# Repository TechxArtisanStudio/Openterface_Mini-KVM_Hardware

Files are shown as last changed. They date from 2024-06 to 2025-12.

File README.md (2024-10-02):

# Welcome to Openterface Mini-KVM Hardware

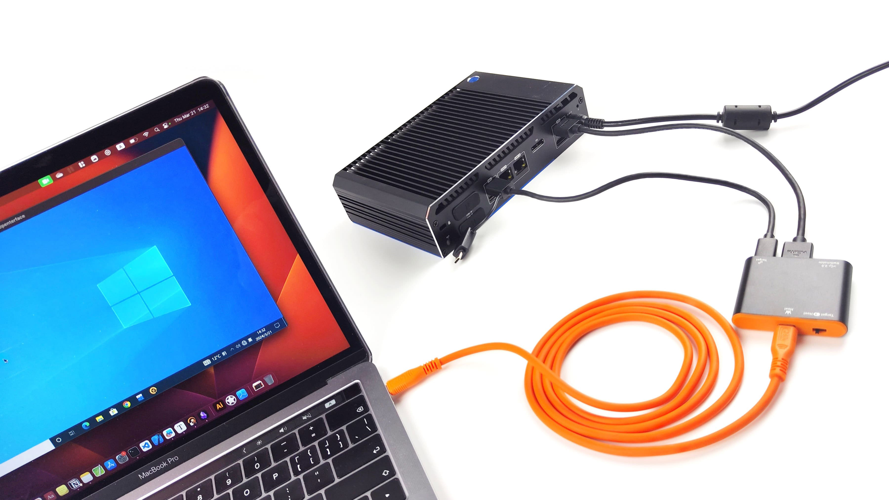
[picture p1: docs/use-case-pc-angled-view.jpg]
use-case-pc-angled-view


## Overview

The [Openterface Mini-KVM](https://openterface.com/) is a compact, feature-rich, and open-source KVM gadget driven by a vibrant [community](https://openterface.com/community/). It allows you to use your own laptop to display and control headless devices directly through a USB and HDMI connection. This KVM-over-USB solution captures video via HDMI and simulates keyboard and mouse inputs. It is particularly useful for a wide range of applications, catering to tech enthusiasts exploring single-board computers, as well as IT professionals troubleshooting headless devices. It eliminates the need for additional monitors, keyboards, and mice, providing a convenient solution in environments where network connections are unreliable or unavailable.

## Hardware Features

The Openterface Mini-KVM PCB board comes with a variety of features designed to provide a seamless and efficient user experience:

- **Compact Design**: Small form factor that fits easily into any setup.
- **HDMI Input**: Captures video from headless devices via HDMI.
- **USB Connectivity**: Simulates keyboard and mouse inputs through a single USB connection.
- **Open Source**: Fully open-source hardware and software, allowing for community-driven development and customization.
- **High Compatibility**: Supports a wide range of devices and operating systems.
- **Durable Build**: The frame uses high-quality anodized aluminum, features a clearly marked housing design, and includes a 3D printed side cover that you can easily reprint yourself if broken.
- **Easy Setup**: Simple plug-and-play functionality with minimal configuration required.
- **Community Support**: Backed by a vibrant and active community for troubleshooting and enhancements.
- **Switchable USB Port**: Features a switchable USB-A 2.0 port that can be toggled between the host and target computers, but not both simultaneously. Switching can be done via a physical toggle on the device or a button in the host application.
- **Extension Pins**: Provides USB 5V power supply, data lines, and ground connections for external components, allowing users to easily add functions to both the target and host computers.

## PCB Design
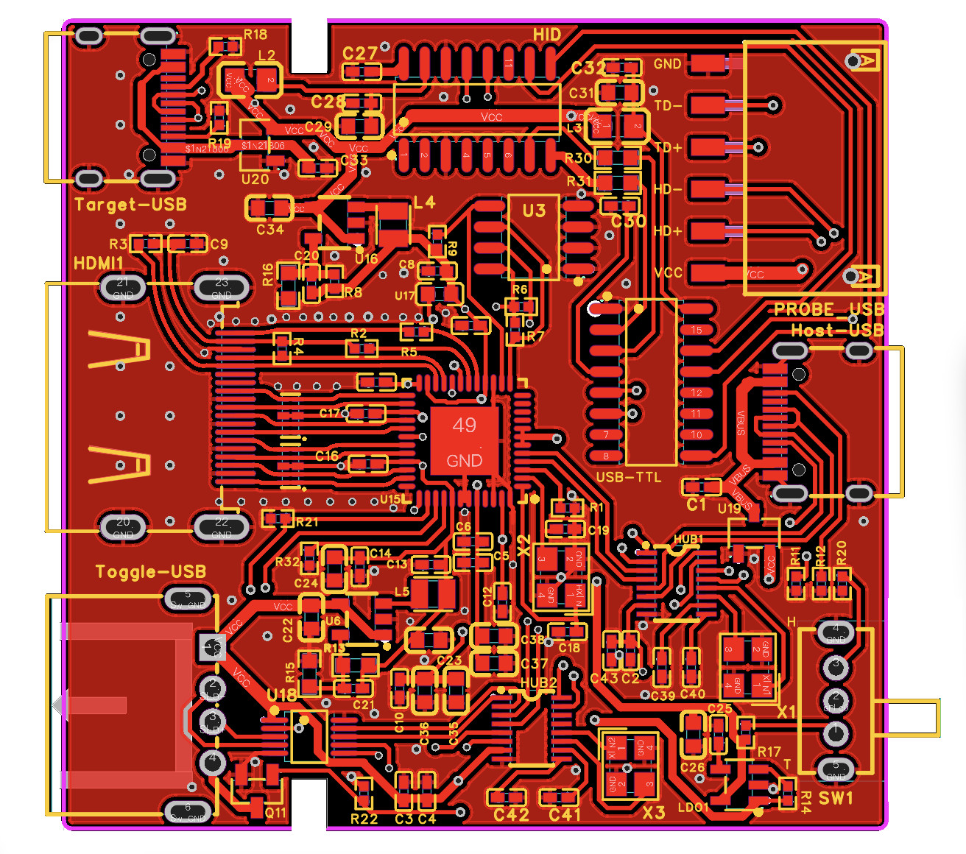
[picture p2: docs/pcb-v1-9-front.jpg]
pcb-v1.9-front

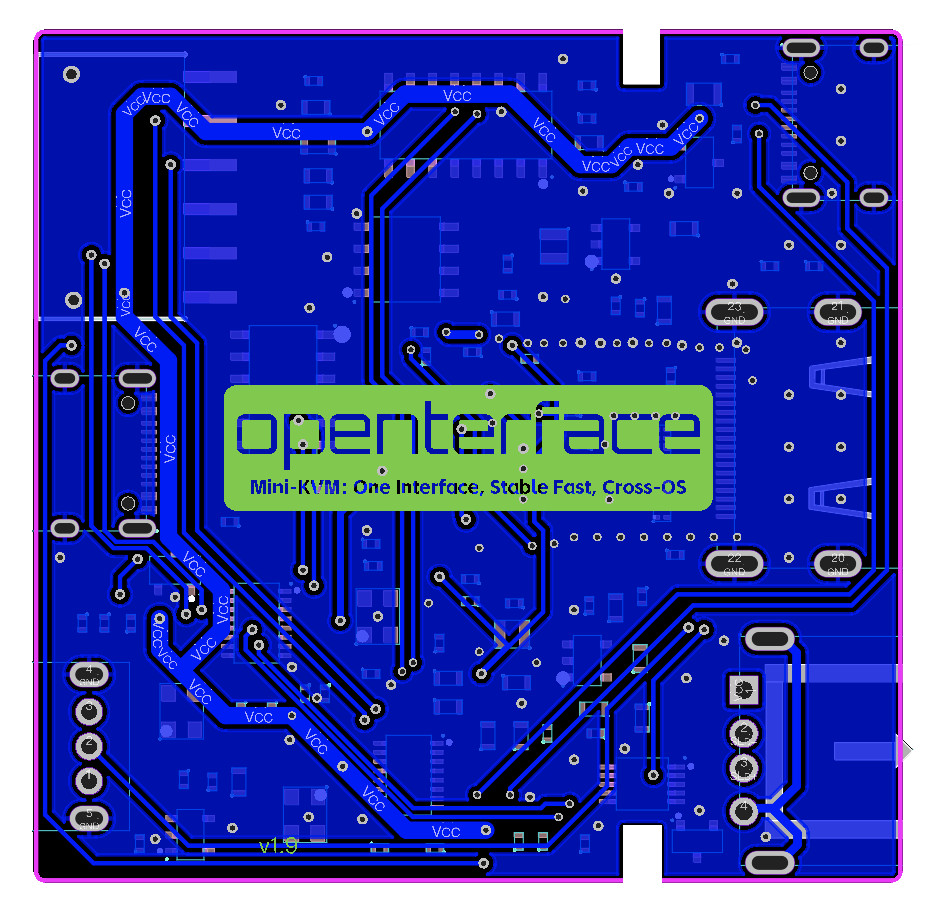
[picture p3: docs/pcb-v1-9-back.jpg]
pcb-v1.9-back


## Software

To use this mini-KVM, the host computer must have one of the following host applications installed: 
- [Openterface_MacOS](https://github.com/TechxArtisanStudio/Openterface_MacOS): For macOS support. The macOS app is also available on Apple's App Store by searching for "Openterface".
- [Openterface_QT](https://github.com/TechxArtisanStudio/Openterface_QT): For Windows and Linux Support.

You can find the installation instructions on the respective GitHub repositories. These open-source host applications are currently under active development. Support for Android and web extensions will be available soon. For more information about the software, please visit the repositories.

## license
- Hardware is released under CERN Open Hardware Licence Version 2 - Strongly Reciprocal
- Its softwares are released under GNU AFFERO GENERAL PUBLIC LICENSE Version 3
- Documentation is released under [CC BY-SA 4.0](https://creativecommons.org/licenses/by-sa/4.0/legalcode)

## Get Involved

[Keen to contribute?](https://openterface.com/contributing/) Fancy joining our team? Drop us an [email](mailto:info@techxartisan.com)!

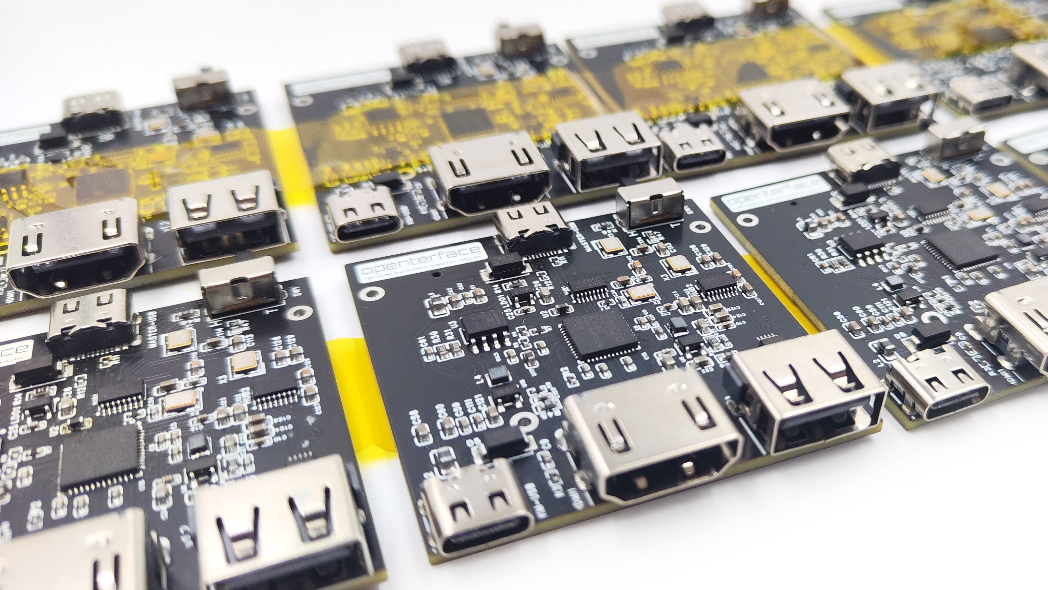
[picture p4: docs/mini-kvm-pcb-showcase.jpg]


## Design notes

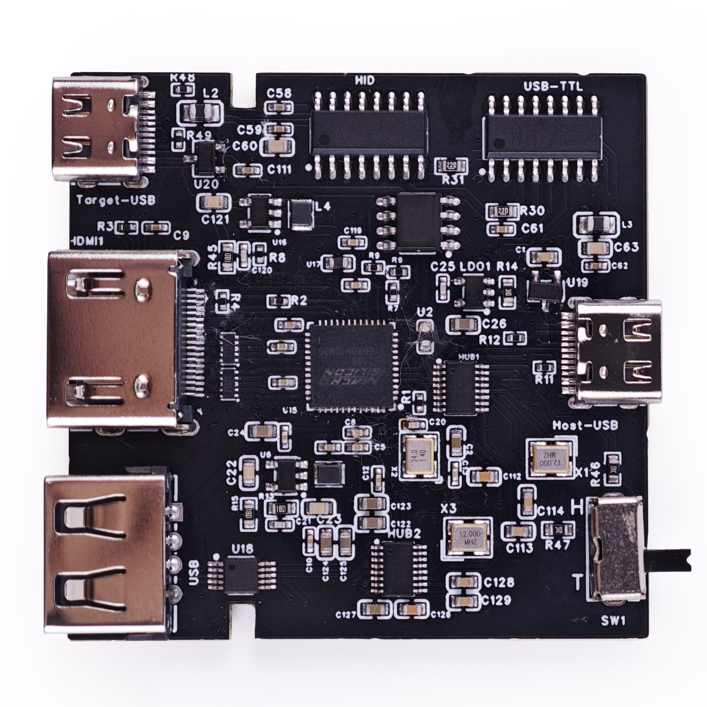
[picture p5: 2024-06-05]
docs/pcb-v1-6-front.jpg

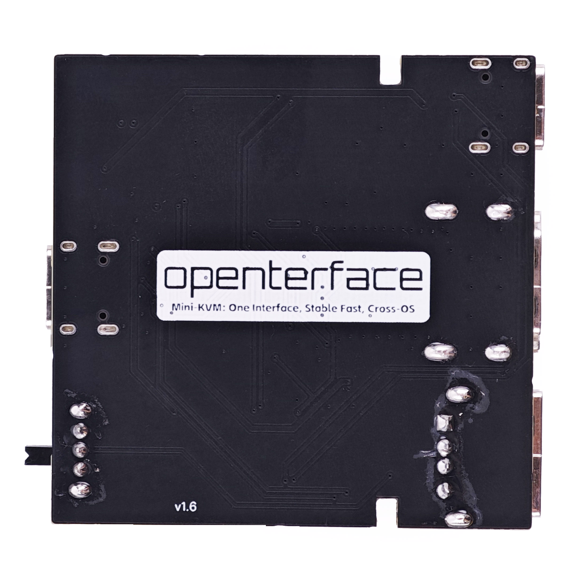
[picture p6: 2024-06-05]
docs/pcb-v1-6-back.jpg

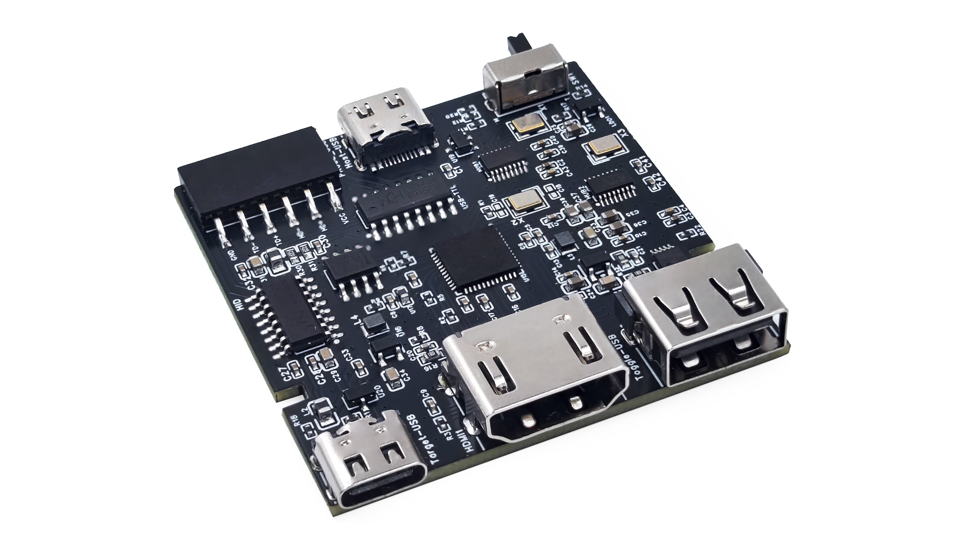
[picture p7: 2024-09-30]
docs/pcb_v1-9.jpg

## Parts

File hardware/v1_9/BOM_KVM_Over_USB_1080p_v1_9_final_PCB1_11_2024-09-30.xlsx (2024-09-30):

No. | Quantity | Comment | Designator | Footprint | Value | Manufacturer Part | Manufacturer
1 | 18 | 100nF | C1,C5,C6,C7,C8,C9,C10,C11,C12,C13,C14,C16,C17,C33,C39,C40,C41,C42 | C0402 | 100nF | CL05B104KO5NNNC | SAMSUNG(三星)
2 | 2 | 1uF | C2,C3 | C0402 | 1uF | CL05A105KA5NQNC | SAMSUNG(三星)
3 | 2 | 10nF | C4,C43 | C0402 | 10nF | CL05B103KB5NNNC | SAMSUNG(三星)
4 | 2 | NC | C18,C19 | C0402 | NC | 0402CG200J500NT | FH(风华)
5 | 2 | 20pF | C20,C21 | C0402 | 20pF | 0402CG200J500NT | FH(风华)
6 | 5 | 10uF | C22,C23,C29,C31,C34 | C0603 | 10uF | CL10A106MA8NRNC | SAMSUNG(三星)
7 | 6 | 22uF | C24,C26,C35,C36,C37,C38 | C0603 | 22uF | CL10A226MQ8NRNC | SAMSUNG(三星)
8 | 1 | 22pF | C25 | C0402 | 22pF | 0402CG220J500NT | FH(风华)
9 | 4 | 100nF | C27,C28,C30,C32 | C0402 | 100nF | CL05B104KB54PNC | SAMSUNG(三星)
10 | 2 | RClamp0524PATCT | D2,D6 | SLP2510P8_L2.5-W1.0-P0.50-BL |  | RClamp0524PATCT | SEMTECH
11 | 1 | HDMI-019S | HDMI1 | HDMI-SMD_HDMI-019S |  | HDMI-019S | SOFNG(硕方)
12 | 1 | CH9329 | HID | SOP-16_L9.9-W3.9-P1.27-LS6.0-BL |  | CH9329 | WCH(南京沁恒)
13 | 2 | TYPE-611A-T3 | Host-USB,Target-USB | USB-C-SMD_TYPE-611A-T3 |  | TYPE-611A-T3 | Yuandi(元迪)
14 | 2 | SL2.1s | HUB1,HUB2 | SSOP-16_L4.6-W2.6-P0.53-LS4.0-BL |  | SL2.1s | CoreChips(和芯润德)
15 | 2 | 10uH | L2,L3 | L0805 | 10uH | MLZ2012M100WT000 | TDK
16 | 2 | 2.2uH | L4,L5 | IND-SMD_L2.0-W1.6 | 2.2uH | CKCS201610-2.2uH/M | CENKER(岑科)
17 | 1 | RT9193-33GB | LDO1 | SOT-23-5_L3.0-W1.7-P0.95-LS2.8-BL |  | RT9193-33GB | RICHTEK(立锜)
18 | 1 | X6511FRS-06-C85D30 | PROBE_USB | HDR-SMD_6P-P2.54-H-F-L11.5 |  | X6511FRS-06-C85D30 | XKB Connectivity(中国星坤)
19 | 1 | SI2302-HXY | Q11 | SOT-23-3_L2.9-W1.3-P1.90-LS2.4-BR |  | SI2302-HXY | HXY MOSFET(华轩阳电子)
20 | 4 | 4.7kΩ | R1,R6,R7,R9 | R0402 | 4.7kΩ | 0402WGF4701TCE | UNI-ROYAL(厚声)
21 | 2 | 1kΩ | R2,R5 | R0402 | 1kΩ | 0402WGF1001TCE | UNI-ROYAL(厚声)
22 | 2 | 47kΩ | R3,R4 | R0402 | 47kΩ | 0402WGF4702TCE | UNI-ROYAL(厚声)
23 | 1 | 680kΩ | R8 | R0402 | 680kΩ | RC0402FR-07680KL | YAGEO(国巨)
24 | 4 | 5.1kΩ | R11,R12,R18,R19 | R0402 | 5.1kΩ | 0402WGF5101TCE | UNI-ROYAL(厚声)
25 | 3 | 150kΩ | R13,R15,R16 | R0603 | 150kΩ | 0603WAF1503T5E | UNI-ROYAL(厚声)
26 | 5 | 10kΩ | R14,R17,R20,R21,R22 | R0402 | 10kΩ | 0402WGF1002TCE | UNI-ROYAL(厚声)
27 | 2 | 22Ω | R30,R31 | R0603 | 22Ω | 0603WAF220JT5E | UNI-ROYAL(厚声)
28 | 1 | NC | R32 | R0402 | NC | 0402WGF0000TCE | UNI-ROYAL(厚声)
29 | 1 | SK12D07VG4 | SW1 | SW-TH_SK12D07VG4 |  | SK12D07VG4 | SHOU HAN(首韩)
30 | 1 | AF 10.0 HC6.3 | Toggle-USB | USB-A-TH_AF-10.0-HC6.3 |  | AF 10.0 HC6.3 | SHOU HAN(首韩)
31 | 1 | AT24C16M/TR | U3 | SOP-8_L4.9-W3.9-P1.27-LS6.0-BL |  | AT24C16M/TR | HGSEMI(华冠)
32 | 2 | MT3520B | U6,U16 | SOT-23-5_L3.0-W1.7-P0.95-LS2.8-BR |  | MT3520B | 西安航天民芯
33 | 1 | MS2109 | U15 | QFN-48_L7.0-W7.0-P0.50-TL-EP4.1
34 | 1 | BLM18PG121SN1D | U17 | L0603 |  | BLM18PG121SN1D | muRata(村田)
35 | 1 | FSUSB42MUX | U18 | MSOP-10_L3.0-W3.0-P0.50-LS5.0-BL |  | FSUSB42MUX | onsemi(安森美)
36 | 2 | CH213K | U19,U20 | SOT-23-3_L2.9-W1.6-P1.90-LS2.8-BR |  | CH213K
37 | 1 | CH340B | USB-TTL | SOIC-16_L9.9-W3.9-P1.27-LS6.0-BL |  | CH340B | WCH(南京沁恒)
38 | 2 | 12MHz | X1,X3 | CRYSTAL-SMD_4P-L3.2-W2.5-BL | 12MHz | TAXM12M4RLBDDT2T | YJX(雅晶鑫)
39 | 1 | 24MHz | X2 | CRYSTAL-SMD_4P-L3.2-W2.5-BL | 24MHz | TXM24M0004322FBCDO00T | YJX(雅晶鑫)

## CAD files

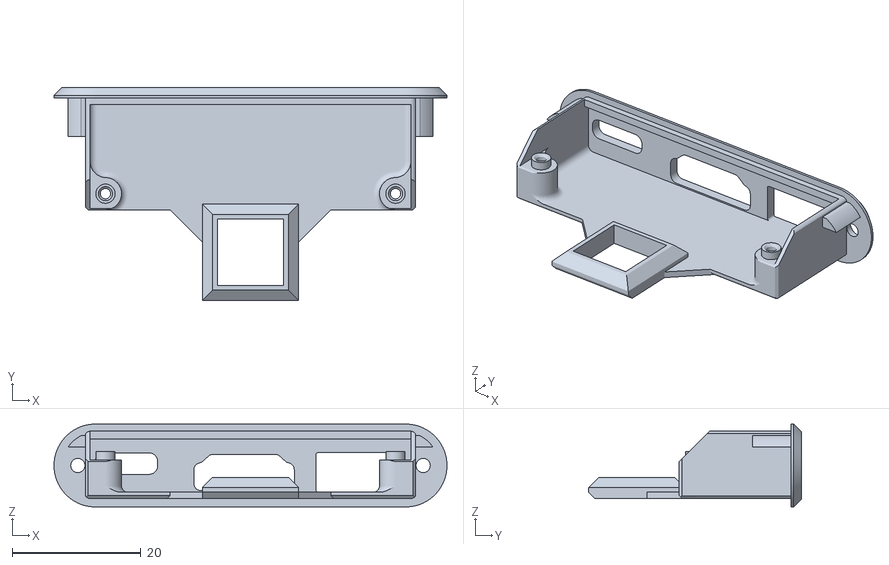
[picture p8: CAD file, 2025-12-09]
models/hdmi-side(Nylon).stl
61.1 x 33.1 x 12.9

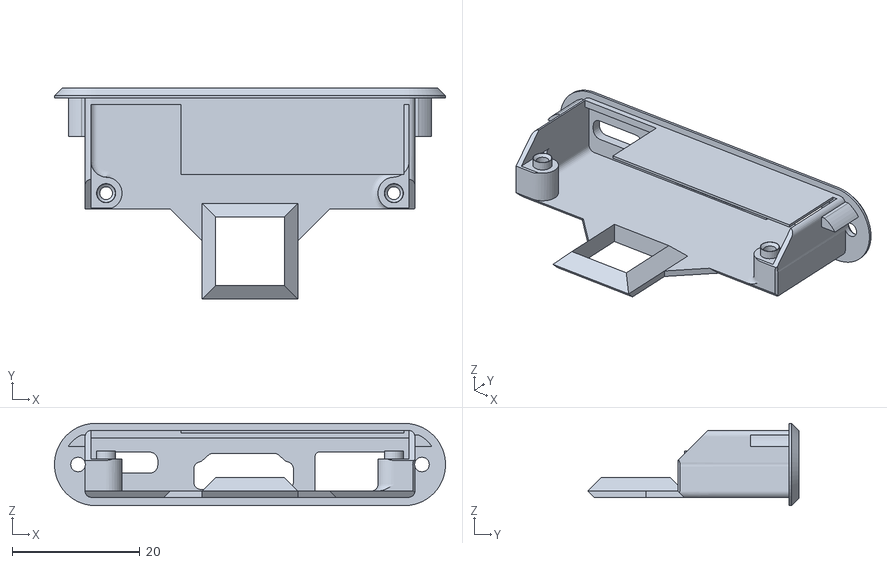
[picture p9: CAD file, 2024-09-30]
models/hdmi-side.stl
61.3 x 33.1 x 12.9

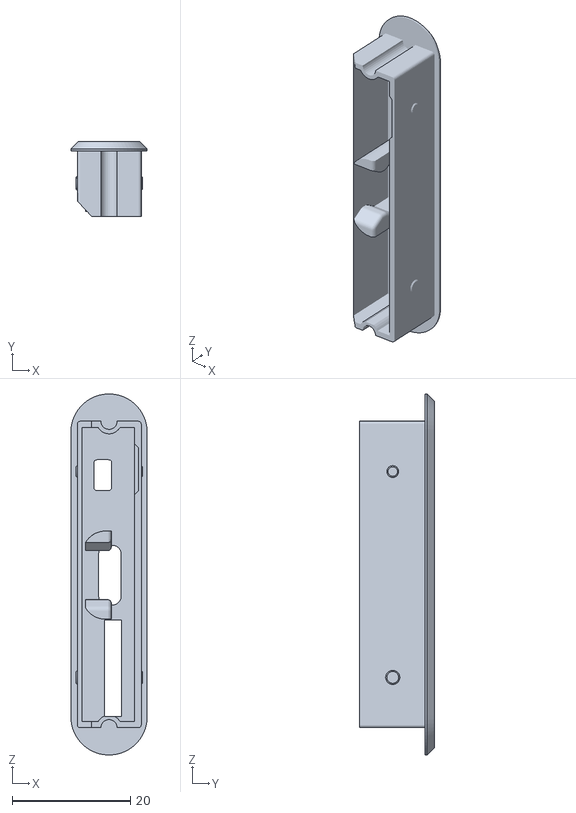
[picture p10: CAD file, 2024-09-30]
models/type-c-side-open.stl
12.9 x 12.6 x 61.0

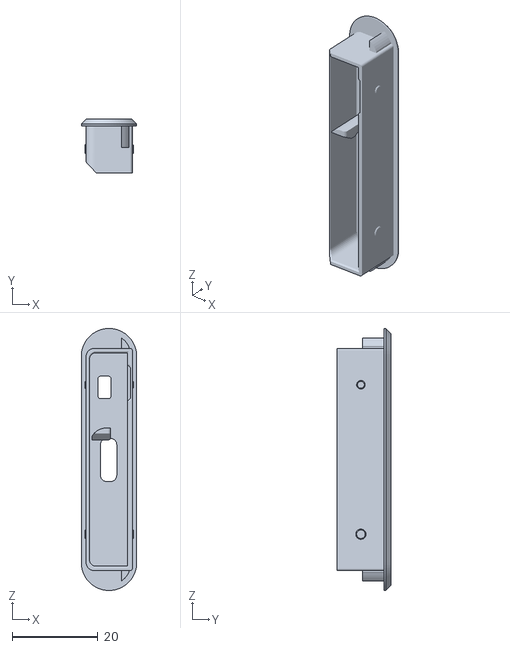
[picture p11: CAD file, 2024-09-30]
models/type-c-side.stl
12.9 x 12.6 x 61.0

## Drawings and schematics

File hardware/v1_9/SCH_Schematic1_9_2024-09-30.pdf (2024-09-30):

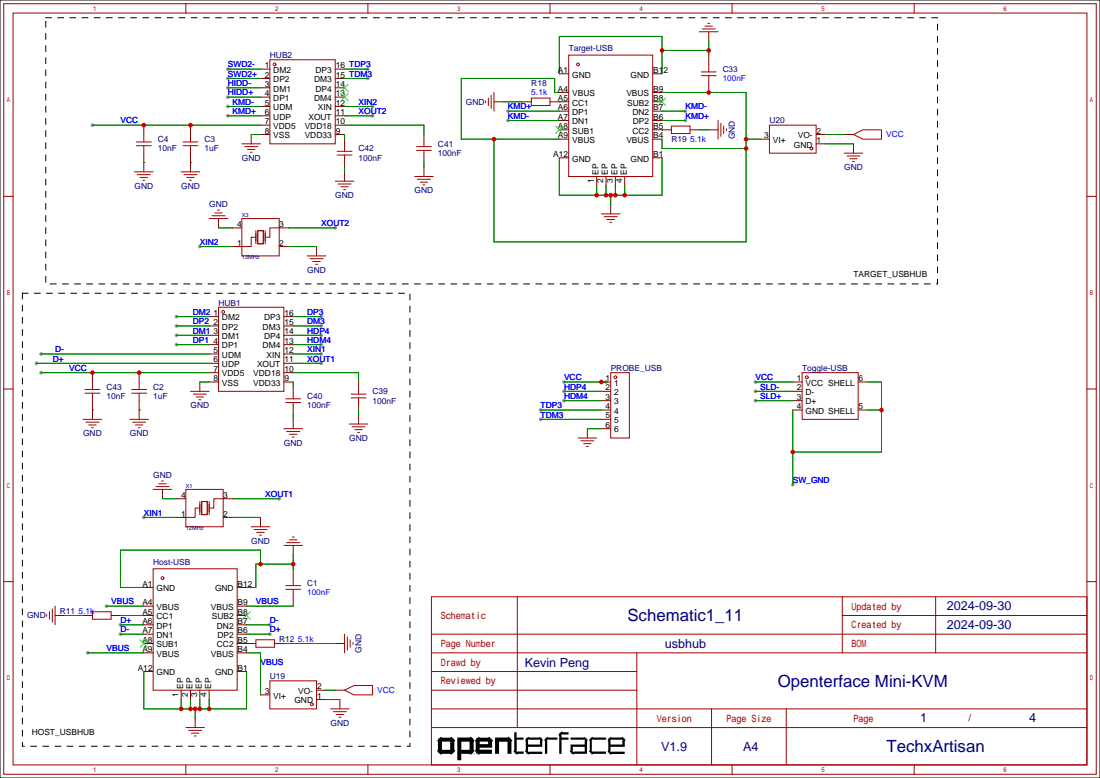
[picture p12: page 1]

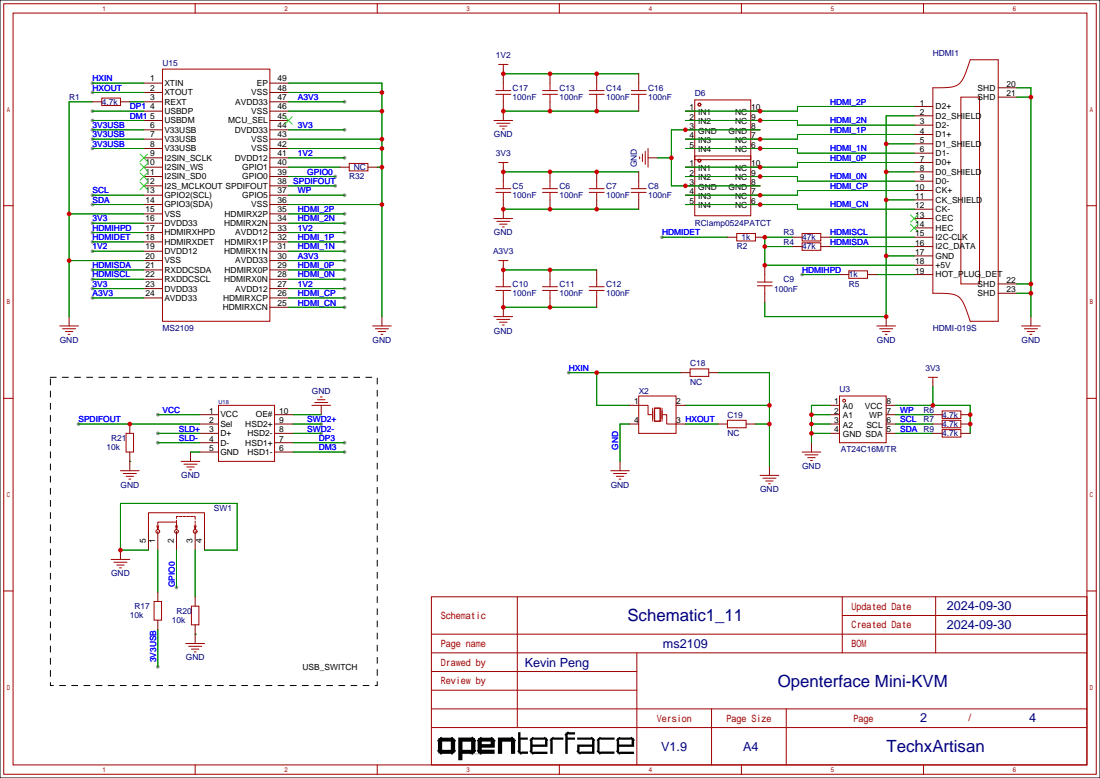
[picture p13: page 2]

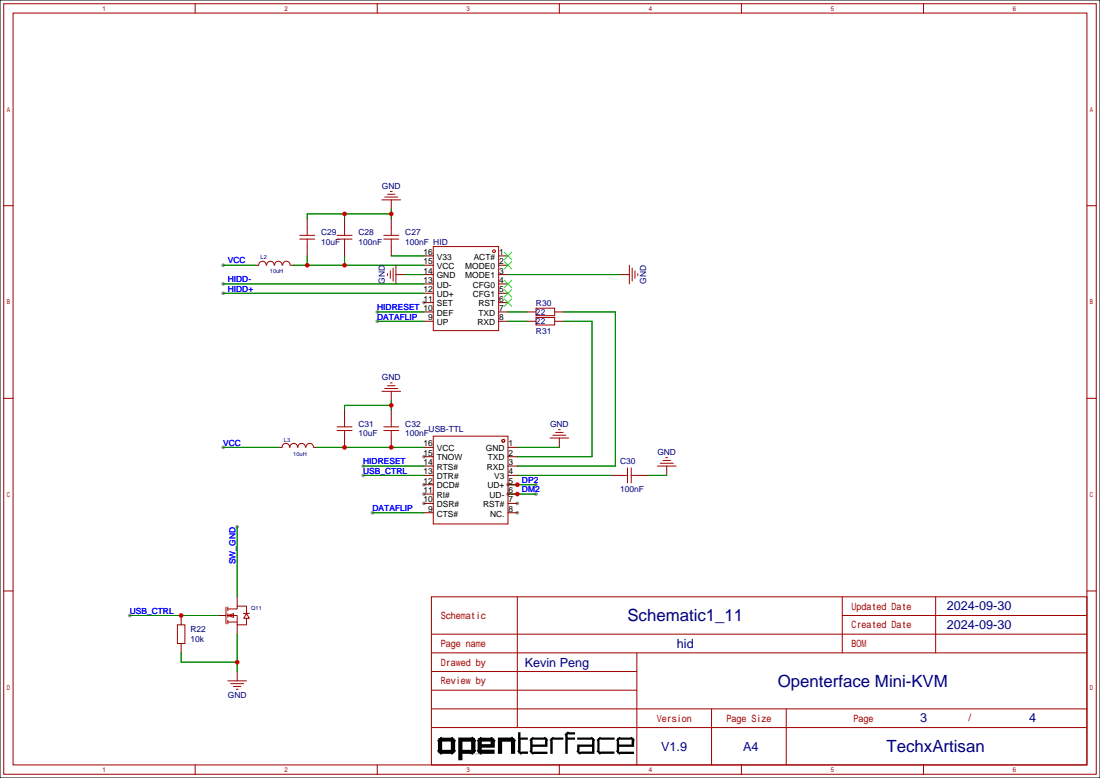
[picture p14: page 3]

DEF 10 SET 11 UD+ 12 UD- 13 GND 14 VCC 15 V33 16

USB-TTL
DSR# 10 RI# 11 DCD# 12 DTR# 13 RTS# 14 TNOW 15 VCC 16

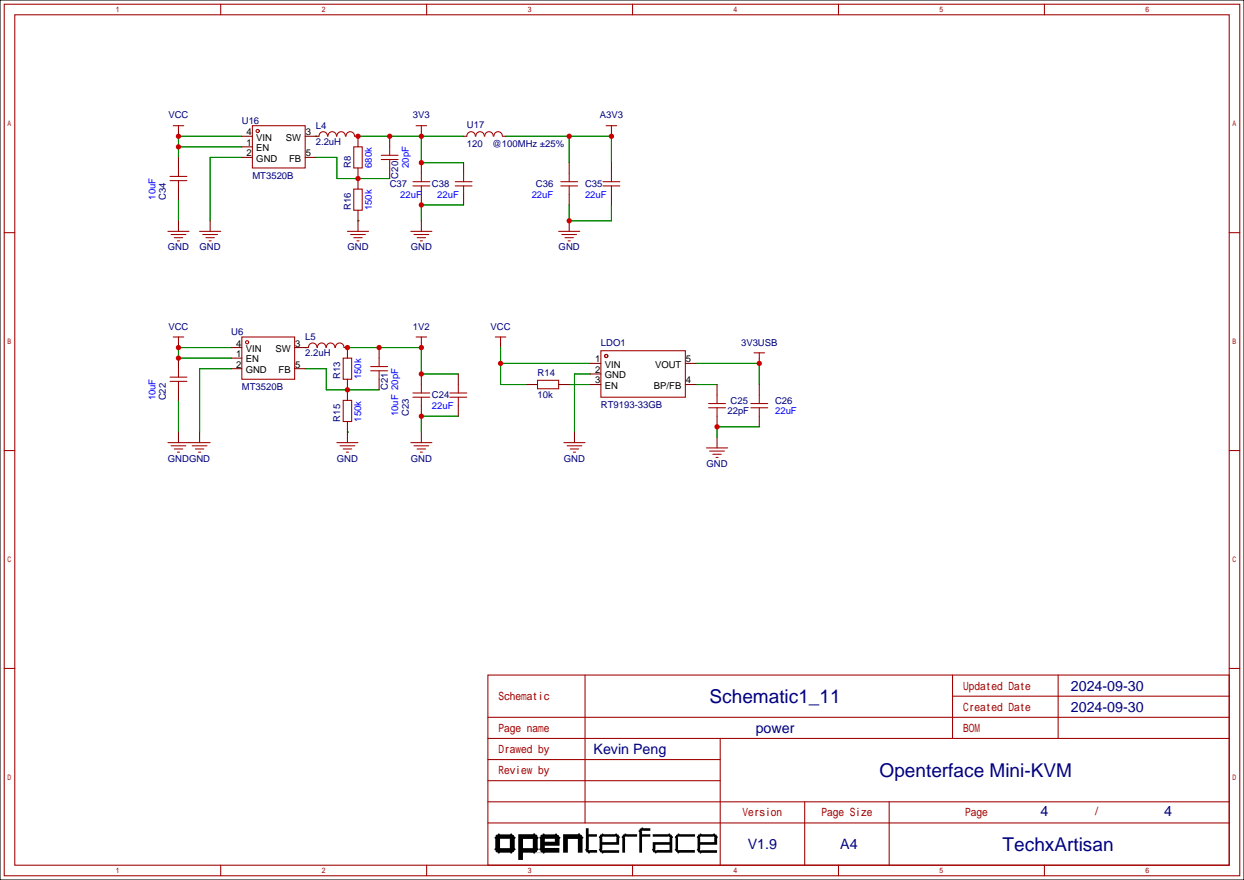
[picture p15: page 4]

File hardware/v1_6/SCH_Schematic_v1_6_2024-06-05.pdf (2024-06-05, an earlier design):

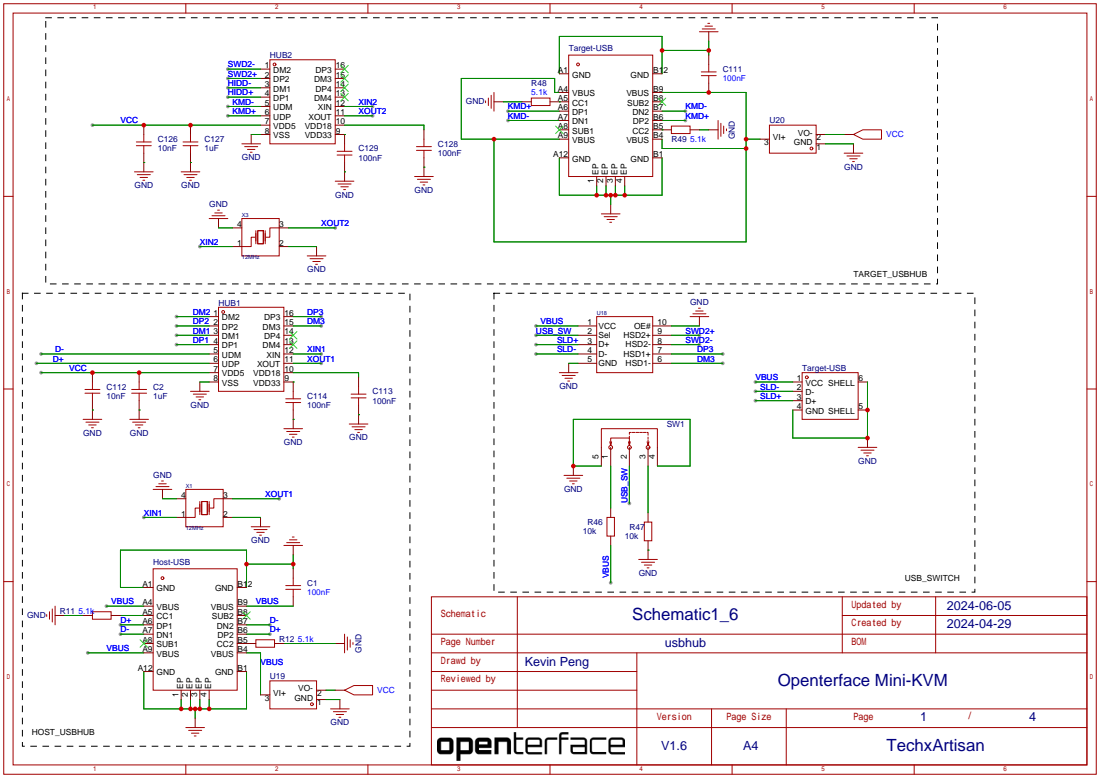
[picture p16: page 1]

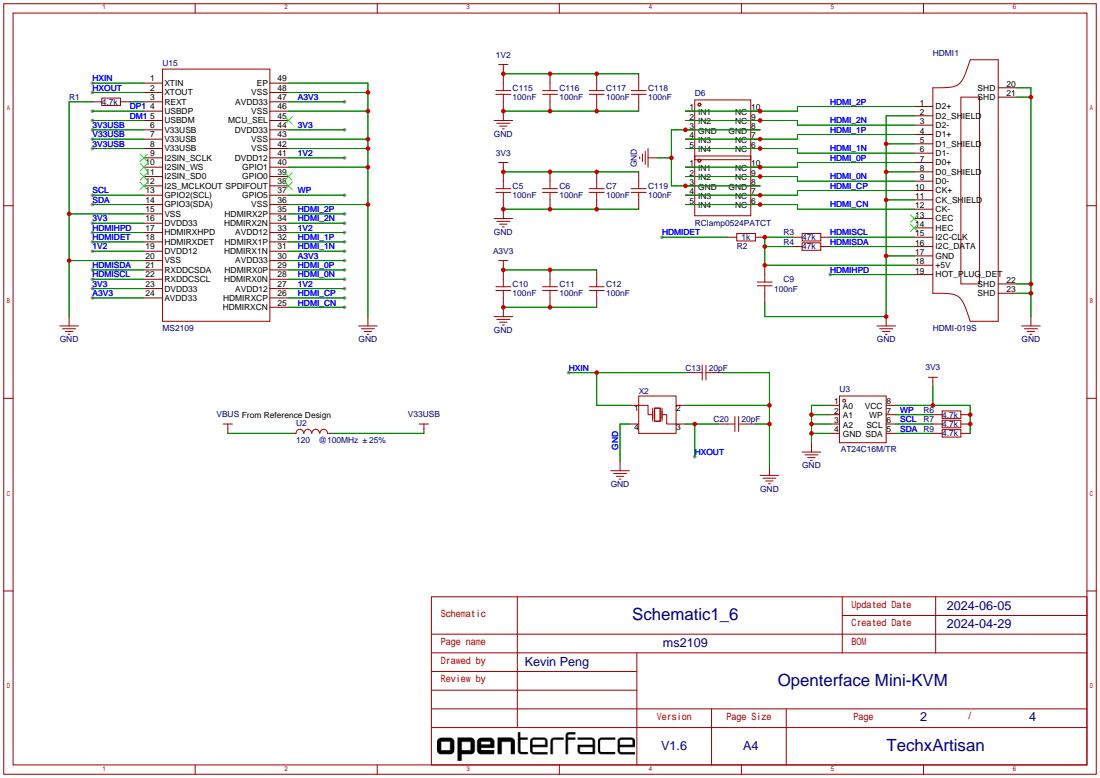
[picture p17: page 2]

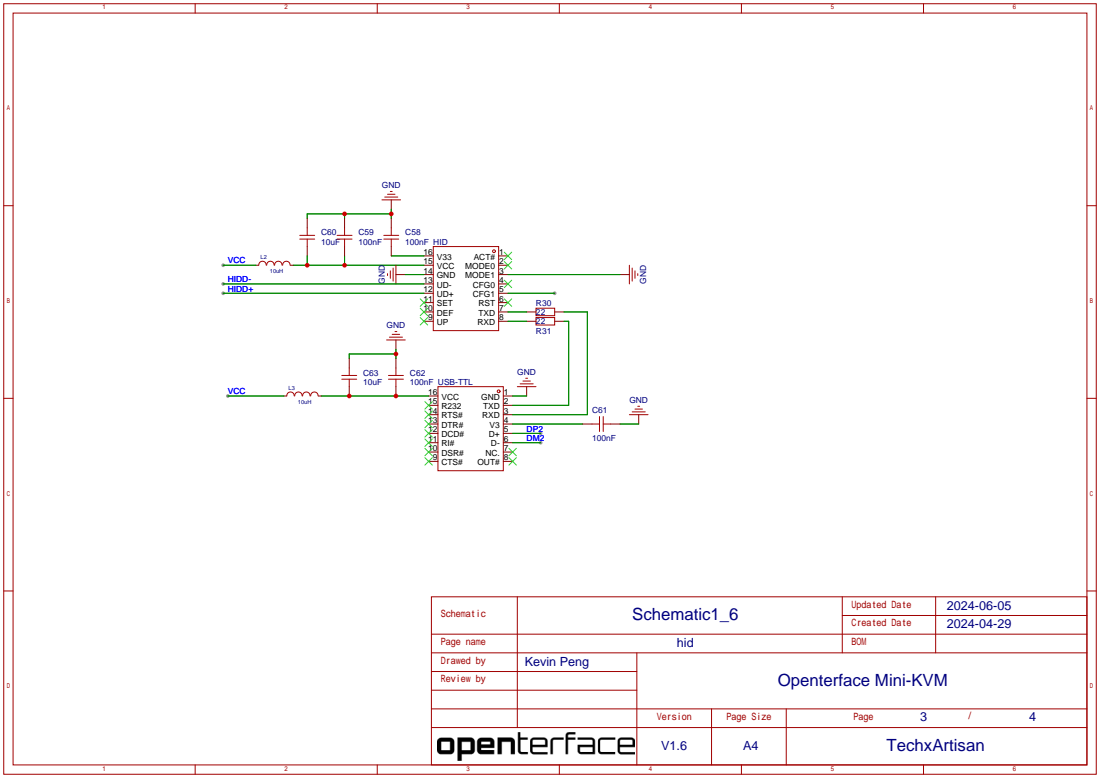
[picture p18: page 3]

DEF 10 SET 11 UD+ 12 UD- 13 GND 14 VCC 15 V33 16

USB-TTL
DSR# 10 RI# 11 DCD# 12 DTR# 13 RTS# 14 R232 15 VCC 16

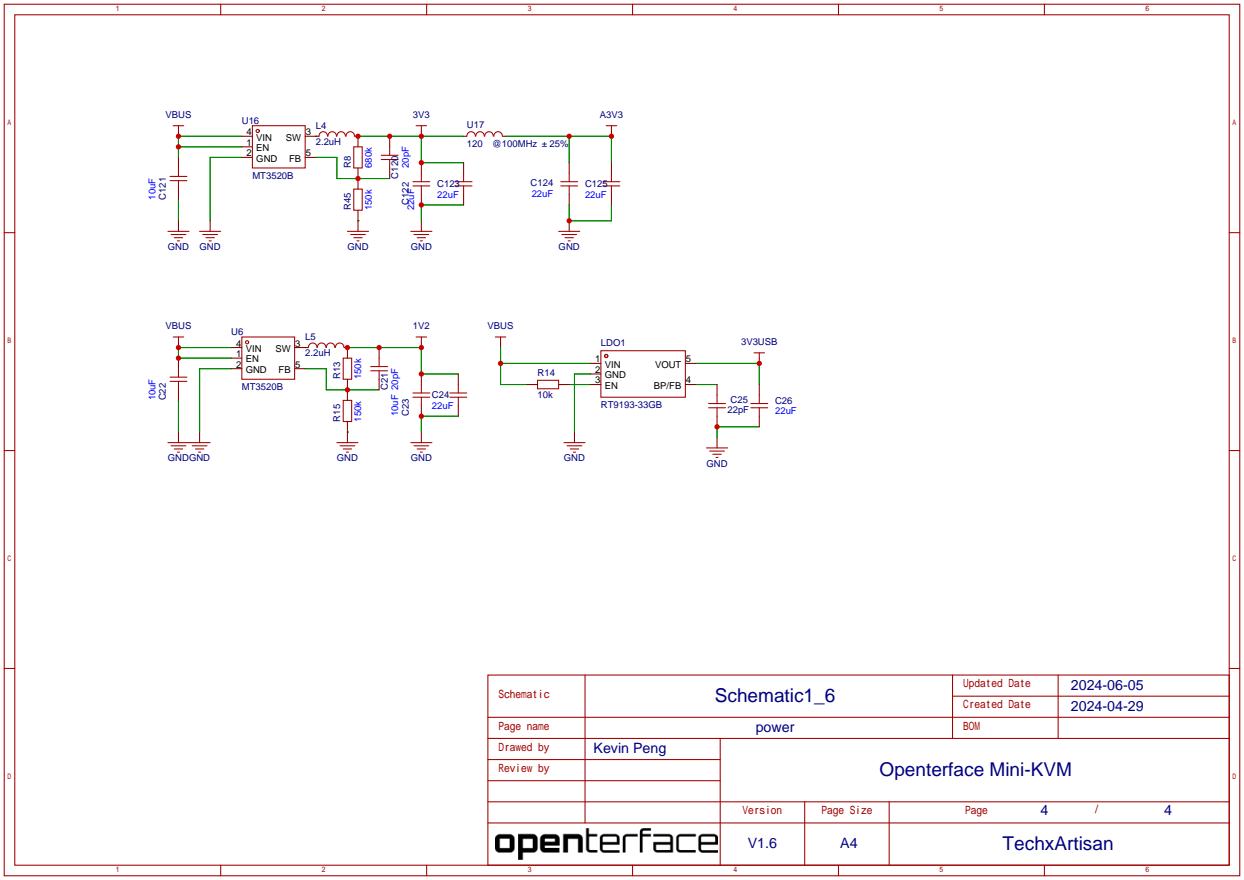
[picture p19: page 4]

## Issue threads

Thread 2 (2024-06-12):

Kashall's Beta Testing Thoughts

kashalls, 2024-06-12:
👋 Hi there!

I was invited to take part in the Beta Testing of Openterface last month, and I wanted to write a document to show my thoughts about the device all in one place, so this is where I will put it.

### 06/11/2024
After originally being accepted to participate in late May of this year, I received the device without any shipping damage. It was well sealed, and considering the travel distance from their studio overseas to the United States it had no other damage. Inside the wrapping was their custom made box with the kit inside.

Included in my beta kit was the Openterface dongle, some stickers, a VGA to HDMI conversion cable, a 3ft orange type c to c cable, a type c to USB with an adapter to type c, and a HDMI cable. I personally find all of the provided cables sturdy. The included zipper shell case has a nice touch on the outside, but lacks branding on the case. Some orange/black text on the shell of the case would be really appealing. The inside of the shell has a nice fabric to prevent scratching, but the border inside next to the zipper is kind of itchy.

The device once plugged in was immediately recognized by Windows and could actually be used as a webcam, if you wanted to share your display on Discord you could do that as well (without the mouse and keyboard capabilities). I had some trouble running the device on some embedded Linux kernels where the uvcvideo kernel module was not built in, but the default kernel from Ubuntu 22.04 LTS and higher have this enabled by default making it plug and play.

Windows seems to have an issue with Openterface when using it through front-panel usb slots. Kevin had told me it was because my case's usb 3.0 ports might have actually been a hub instead which can cause issues since Openterface is actually using a USB hub in its design. I tried using Openterface from an actual Type C port and as well from a independently powered USB hub which worked marvelously.

RyanWor, 2024-06-13:
For what it's worth, I've been using the openterface with a MSI Z390 based Windows 11 desktop and it's been working great via the front USB-C on my Fractal Design case. As suggested, it might be a hub or a lower speed USB3 port on your case.

kashalls, 2024-06-13:
> For what it's worth, I've been using the openterface with a MSI Z390 based Windows 11 desktop and it's been working great via the front USB-C on my Fractal Design case. As suggested, it might be a hub or a lower speed USB3 port on your case.

That's what I was looking into, it seems that all of my usb ports eventually cause this "reset" to happen with the device where openterface disconnects and reconnects to Windows, but this is solved once its plugged directly into the motherboard's usb c slot.

Closed 2024-06-12.

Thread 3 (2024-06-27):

Pick&Place File / PCB Source Files Not Present

jakergirard, 2024-06-27:
Hello, the Pick&Place file (CPL) for the PCB is not present in the "hardware" folder with the gerber files, BOM, etc. This and/or the PCB project files should be made available so the PCB can be ordered as needed by future users.

There should also be firmware and flash methods noted in this repo.

Laikulo, 2025-01-31:
I can't speak to the missing manufacturing files, but there actually isn't any bespoke firmware. I was kinda surprised, as the first thing I usually do with these kinds of devices is update. The device is actually a combintion of a COTS usb2 capture card, a uart to hid part, and a bit of glue (hubs and a usb->ttluart).

AFAICT, the firmware in the HID part can't be field upgraded (it might be maskrom), though there is firmware on the capture card which appears to be, but I somewhat doubt it is running foss fw.

kevinzjpeng, 2025-02-11:
Re @jakergirard

Thank you for pointing out the absence of the Pick & Place file (CPL) in the repository. I've now added the file to the "hardware" folder in the repository. You can find it in this [commit](https://github.com/TechxArtisanStudio/Openterface_Mini-KVM_Hardware/commit/e693f1bfffb1219b9670ef9374f8088ae122a109).

This file should now allow future users to order the PCB with all necessary manufacturing files, including the BOM, Gerber files, and the CPL (Pick & Place file).

Before proceeding, please remember to review our project's [license](https://github.com/TechxArtisanStudio/Openterface_Mini-KVM_Hardware/blob/main/LICENSE) to ensure compliance with its terms. We hope everything is clear and that you have all the resources you need to get started.

Happy building, and feel free to reach out if you encounter any issues or have further questions!

---

Re @Laikulo:

Thank you for your insights regarding the firmware. You're correct that we do not provide any custom, open-source, or user-modifiable firmware for this project. The device relies on a combination of standard components, including:
- A **MacroSilicon MS2109 USB 2.0 video capture chip** (a widely-used, off-the-shelf component),
- Some glue logic (hubs and a USB-to-TTL UART converter).

Additionally, as you correctly noted, the **UART-to-HID functionality** is actually provided by the **MS2109 chip** itself, rather than being a separate component. This functionality allows the device to communicate over USB using HID protocols.

Regarding the firmware on the MS2109:
- The MS2109 chip does include firmware, but it was developed by MacroSilicon under an NDA agreement. This firmware enables specific features, such as using the MS2109's GPIO and SPDIF address to control the switchable USB port.
- Unfortunately, due to the NDA, we are unable to share or distribute this firmware. However, if you're interested in exploring the firmware further, you can attempt to dump it yourself. There are also several open-source reverse engineering projects for the MS2109 available on GitHub, such as: https://github.com/amnemonic/MacroSilicon
These projects may provide useful insights into how the MS2109 operates and could serve as a starting point for further exploration.

We understand the importance of transparency, but the NDA prevents us from distributing the firmware. However, the hardware design files are now complete, and we hope this will enable users to replicate and build upon the project.

Closed 2025-02-11.

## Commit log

2024-06-05 update hardware info
    [Openterface_BOM_v1_6_2024-06-05.csv, hdmi-side.stl, type-c-side.stl]
2024-06-05 Add an image of PC use case
2024-06-10 upload Gerber Files
    [Drill_NPTH_Through.DRL, Drill_PTH_Through.DRL, Drill_PTH_Through_Via.DRL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]
2024-09-30 upload v1.9
    [BOM_KVM_Over_USB_1080p_v1_9_final_PCB1_11_2024-09-30.xlsx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]
2024-10-02 Update v1.9 pcb image and add hardware features
2025-02-11 Add PickAndPlace file for version 1.9
    [PickAndPlace_v1_9.xlsx]
2025-12-09 hdmi-side(Nylon)
    HDMI side nylon printed version
    [hdmi-side(Nylon).stl]
